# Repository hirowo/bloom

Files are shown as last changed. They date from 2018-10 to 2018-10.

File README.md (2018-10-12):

# Bloom
ArduinoNanoブートローダー入り小型電飾モジュール

## 概要
フルカラーLED(WS2812B)をArduinoでコントロールするとき、
Arduinoのサイズが大きく小型のものに組み込みにくい、ということはありませんか？

本モジュールは、ArduinoNanoのブートローダーが組み込まれた小型のモジュールで、
衣装や小道具など、小型のものに組み込むことができます。

もちろん、ArduinoIDEでプログラムの開発を行うことができ、
プログラムを書き込むためのUSBシリアル変換モジュールも搭載しています。

## 特徴
本モジュールは2.4Aまで電流を流せるようにしており、
1個あたり最大50mA程度流すフルカラーLEDであれば、4,50個程度であれば光らせられます。

また、小型化のためおおよそのピンは削ってありますが、
アナログ入力ピン×2とボタンが実装されており、動作のトリガーとして利用できます。

## 使用可能ピン
フルカラーLEDシリアルピン:6  
基板実装ボタン:7  
A3ピン:A3  
A4ピン:A4  

## スペック
サイズ：36×20×5mm  
USBシリアル変換モジュール：FT232RL  

## ArduinoIDEでプログラムを書き換える方へ
ArduinoIDEのツールの設定は、ボード="Arduino Nano"、プロセッサ="ATmega328P"にしてください。

## （自作する人向け）ブートローダー及びヒューズ設定
下記サイトのNano3.1参照。  
https://trac.switch-science.com/wiki/ArduinoFuse#Nano3.1

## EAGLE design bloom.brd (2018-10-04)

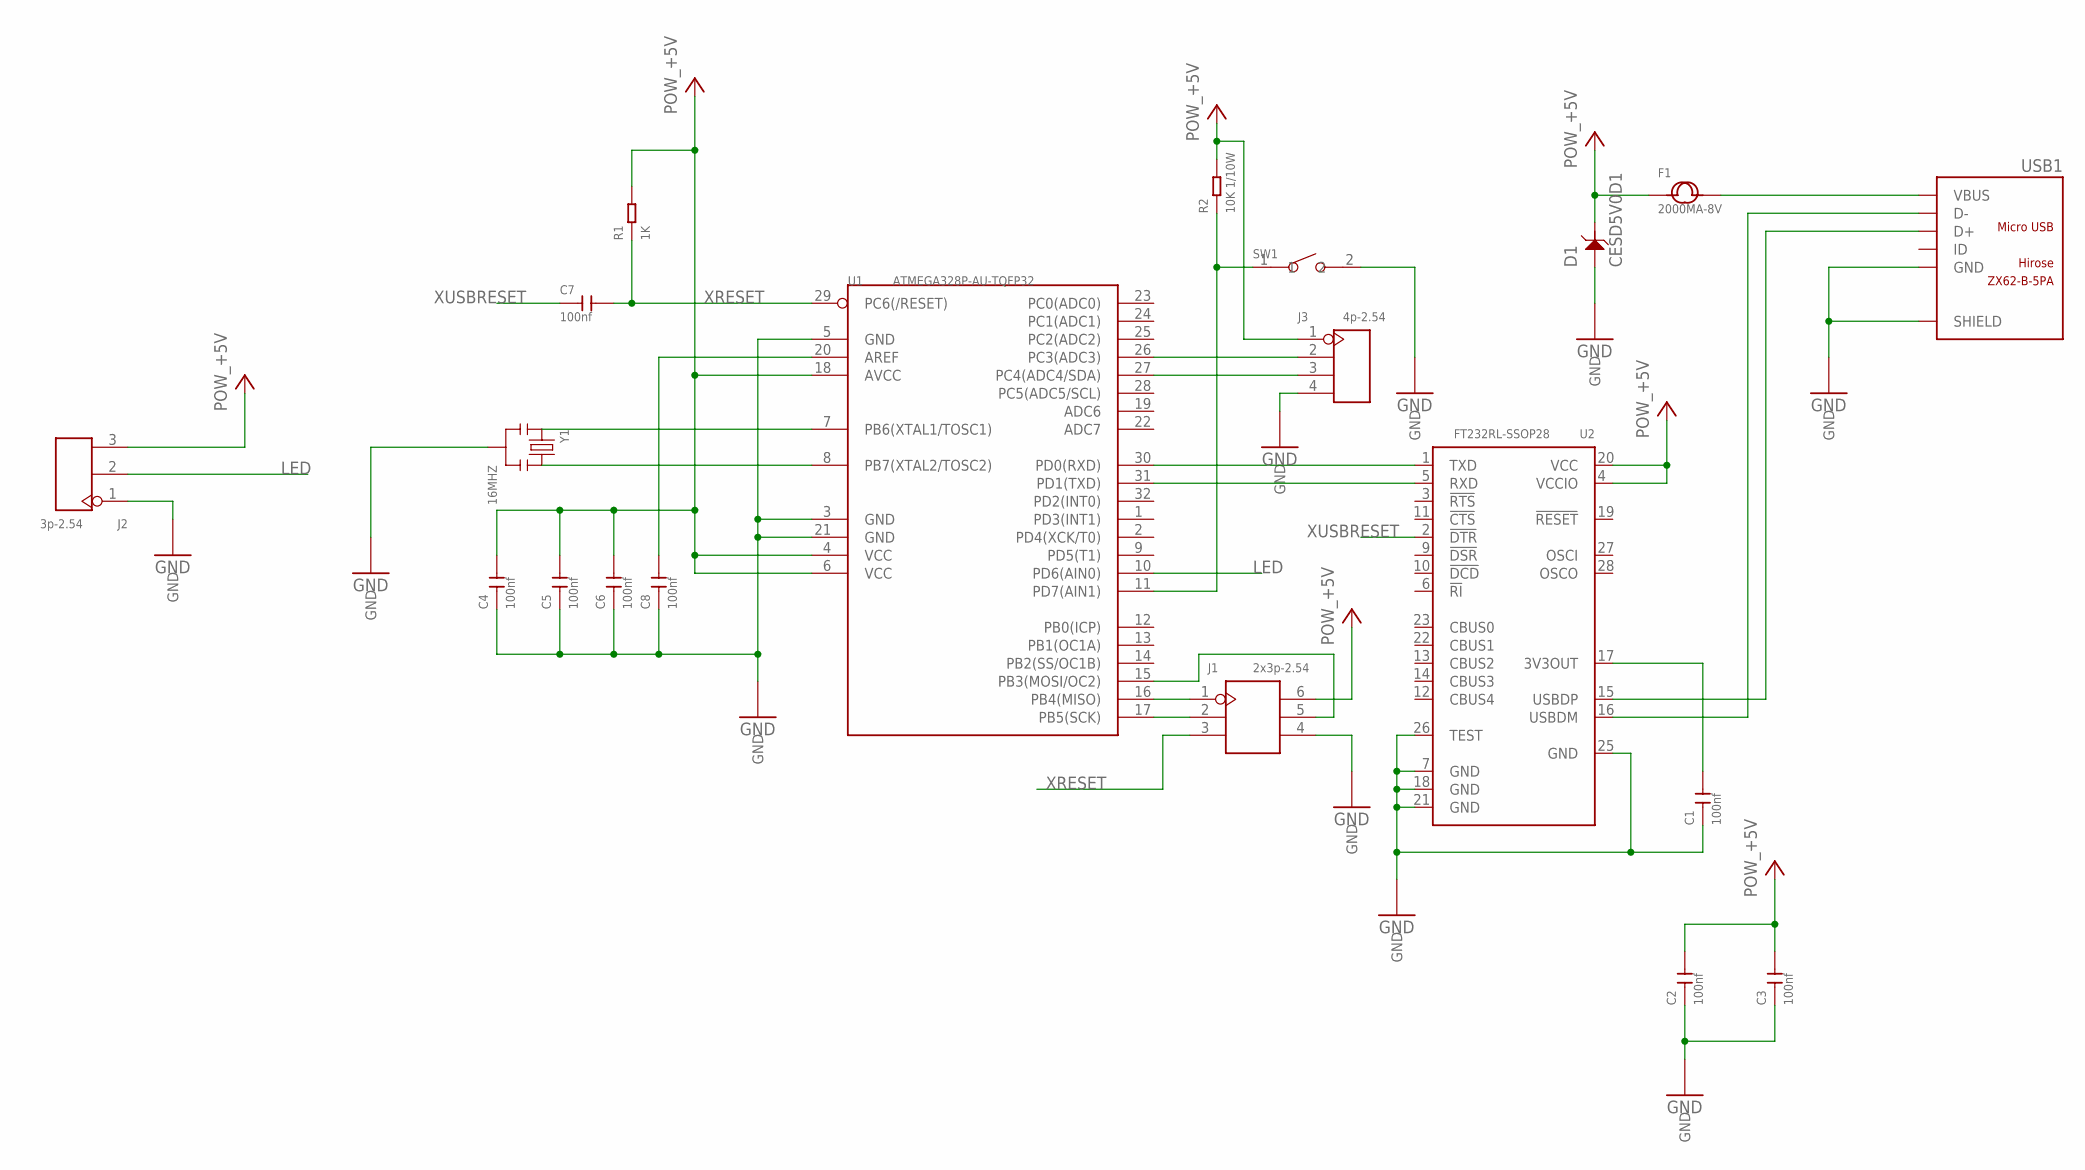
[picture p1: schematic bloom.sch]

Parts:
C1, C2, C3, C4, C5, C6, C7, C8: 100nf; C0402
D1: CESD5V0D1; SOD-123
F1: 2000MA-8V; F1210
J1: 2x3p-2.54; H2X3-2.54
J2: 3p-2.54; H3-2.54
J3: 4p-2.54; H4-2.54
R1: 1K; R0603
R2: 10K 1/10W; R0603
SW1: SMD-BUTTON(2P-3.0X2.5X1.2+0.4MM)-B3U-1000P-2P-SMD; SW2-2.6-3.0X2.5X1.2+0.4MM
U1: ATMEGA328P-AU-TQFP32; TQFP32-0.8-7X7MM
U2: FT232RL-SSOP28; SSOP28-0.65-10.2X5.2MM
USB1: ZX62-B-5PA; MICRO-USB5+6P-SMD-0.65-AB
Y1: 16MHZ; X3-SMD-3.6X1.3X0.8MM

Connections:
+5V: C2.2, C3.2, C4.2, C5.2, C6.2, D1.- (2), F1.1, J1.6, J2.3, J3.1, R1.2, R2.2, U1.4 (VCC), U1.6 (VCC), U1.18 (AVCC), U2.4 (VCCIO), U2.20 (VCC)
GND: C1.1, C2.1, C3.1, C4.1, C5.1, C6.1, C8.1, D1.+ (1), J1.4, J2.1, J3.4, SW1.2, U1.3 (GND), U1.5 (GND), U1.21 (GND), U2.7 (GND), U2.18 (GND), U2.21 (GND), U2.25 (GND), U2.26 (TEST), USB1.5 (GND), USB1.P1 (SHIELD), USB1.P2 (SHIELD), USB1.P3 (SHIELD), USB1.P4 (SHIELD), USB1.P5 (SHIELD), USB1.P6 (SHIELD), Y1.2
LED: J2.2, U1.10 (PD6(AIN0))
unnamed: C8.2, U1.20 (AREF)
unnamed: U1.30 (PD0(RXD)), U2.1 (TXD)
unnamed: U1.7 (PB6(XTAL1/TOSC1)), Y1.1
unnamed: U1.31 (PD1(TXD)), U2.5 (RXD)
unnamed: U2.15 (USBDP), USB1.3 (D+)
unnamed: U2.16 (USBDM), USB1.2 (D-)
unnamed: U1.8 (PB7(XTAL2/TOSC2)), Y1.3
unnamed: J1.1, U1.16 (PB4(MISO))
unnamed: J1.2, U1.17 (PB5(SCK))
unnamed: J1.5, U1.15 (PB3(MOSI/OC2))
unnamed: R2.1, SW1.1, U1.11 (PD7(AIN1))
unnamed: C1.2, U2.17 (3V3OUT)
unnamed: J3.2, U1.26 (PC3(ADC3))
unnamed: J3.3, U1.27 (PC4(ADC4/SDA))
VBUS: F1.2, USB1.1 (VBUS)
XRESET: C7.2, J1.3, R1.1, U1.29 (PC6(/RESET))
XUSBRESET: C7.1, U2.2 (!DTR)

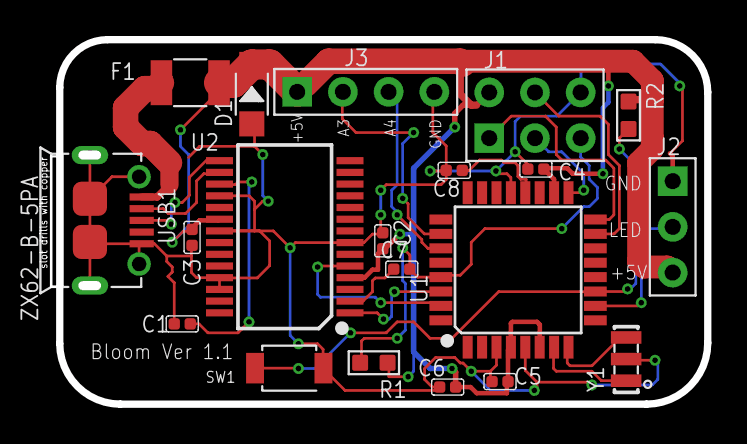
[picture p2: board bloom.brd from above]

Board: 2 copper layers, 36.0 x 20.2 mm, 20 parts (0 on the bottom side), 20 nets.

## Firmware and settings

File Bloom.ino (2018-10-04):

#include <Adafruit_NeoPixel.h>

#ifdef __AVR__
#include <avr/power.h>
#endif

//Bloom関連ピン
#define PIN_LED   6
#define PIN_BTN   7
#define PIN_A3    A3
#define PIN_A4    A4

#define LED_NUM       (40) // LEDの数
#define LED_MAX_SAT   80  // 最大彩度

// ボタン状態
#define PRESS_NONE 0
#define PRESS_NORMAL 1
#define PRESS_LONG 2

#define LONG_PRESS_MS 2000 // 長押し検知時間

// ガンマ補正データ
const uint8_t PROGMEM gamma8[] = {
  0,  0,  0,  0,  0,  0,  0,  0,  0,  0,  0,  0,  0,  0,  0,  0,
  0,  0,  0,  0,  0,  0,  0,  0,  0,  0,  0,  0,  1,  1,  1,  1,
  1,  1,  1,  1,  1,  1,  1,  1,  1,  2,  2,  2,  2,  2,  2,  2,
  2,  3,  3,  3,  3,  3,  3,  3,  4,  4,  4,  4,  4,  5,  5,  5,
  5,  6,  6,  6,  6,  7,  7,  7,  7,  8,  8,  8,  9,  9,  9, 10,
  10, 10, 11, 11, 11, 12, 12, 13, 13, 13, 14, 14, 15, 15, 16, 16,
  17, 17, 18, 18, 19, 19, 20, 20, 21, 21, 22, 22, 23, 24, 24, 25,
  25, 26, 27, 27, 28, 29, 29, 30, 31, 32, 32, 33, 34, 35, 35, 36,
  37, 38, 39, 39, 40, 41, 42, 43, 44, 45, 46, 47, 48, 49, 50, 50,
  51, 52, 54, 55, 56, 57, 58, 59, 60, 61, 62, 63, 64, 66, 67, 68,
  69, 70, 72, 73, 74, 75, 77, 78, 79, 81, 82, 83, 85, 86, 87, 89,
  90, 92, 93, 95, 96, 98, 99, 101, 102, 104, 105, 107, 109, 110, 112, 114,
  115, 117, 119, 120, 122, 124, 126, 127, 129, 131, 133, 135, 137, 138, 140, 142,
  144, 146, 148, 150, 152, 154, 156, 158, 160, 162, 164, 167, 169, 171, 173, 175,
  177, 180, 182, 184, 186, 189, 191, 193, 196, 198, 200, 203, 205, 208, 210, 213,
  215, 218, 220, 223, 225, 228, 231, 233, 236, 239, 241, 244, 247, 249, 252, 255
};

// Parameter 1 = number of pixels in strip
// Parameter 2 = Arduino pin number (most are valid)
// Parameter 3 = pixel type flags, add together as needed:
//   NEO_KHZ800  800 KHz bitstream (most NeoPixel products w/WS2812 LEDs)
//   NEO_KHZ400  400 KHz (classic 'v1' (not v2) FLORA pixels, WS2811 drivers)
//   NEO_GRB     Pixels are wired for GRB bitstream (most NeoPixel products)
//   NEO_RGB     Pixels are wired for RGB bitstream (v1 FLORA pixels, not v2)
//   NEO_RGBW    Pixels are wired for RGBW bitstream (NeoPixel RGBW products)
Adafruit_NeoPixel strip = Adafruit_NeoPixel(LED_NUM, PIN_LED, NEO_GRB + NEO_KHZ800);

void hsv2rgb(float h, float s, float v, uint8_t colors[3]) {
  int i;
  float f, p, q, t;

  h = max(0.0, min(360.0, h));
  s = max(0.0, min(100.0, s));
  v = max(0.0, min(100.0, v));

  s /= 100;
  v /= 100;

  if (s == 0) {
    // Achromatic (grey)
    colors[0] = colors[1] = colors[2] = round(v * 255);
    return;
  }

  h /= 60; // sector 0 to 5
  i = floor(h);
  f = h - i; // factorial part of h
  p = v * (1 - s);
  q = v * (1 - s * f);
  t = v * (1 - s * (1 - f));
  switch (i) {
    case 0:
      colors[0] = round(255 * v);
      colors[1] = round(255 * t);
      colors[2] = round(255 * p);
      break;
    case 1:
      colors[0] = round(255 * q);
      colors[1] = round(255 * v);
      colors[2] = round(255 * p);
      break;
    case 2:
      colors[0] = round(255 * p);
      colors[1] = round(255 * v);
      colors[2] = round(255 * t);
      break;
    case 3:
      colors[0] = round(255 * p);
      colors[1] = round(255 * q);
      colors[2] = round(255 * v);
      break;
    case 4:
      colors[0] = round(255 * t);
      colors[1] = round(255 * p);
      colors[2] = round(255 * v);
      break;
    default: // case 5:
      colors[0] = round(255 * v);
      colors[1] = round(255 * p);
      colors[2] = round(255 * q);
  }
}

void setLEDColor(float hue, float sat, float val) {
  uint8_t rgb_colors[3];

  //getRGB(hue, sat, val, rgb_colors); // converts HSB to RGB
  hsv2rgb(hue, sat, val, rgb_colors);
  for (uint8_t i = 0; i < LED_NUM; i++) {
    strip.setPixelColor(i,
                        pgm_read_byte(&gamma8[rgb_colors[0]]),
                        pgm_read_byte(&gamma8[rgb_colors[1]]),
                        pgm_read_byte(&gamma8[rgb_colors[2]]));
  }
  strip.show();
}

void setup() {
  pinMode(PIN_BTN, INPUT);
  
  strip.begin();
  strip.clear();
  strip.show();

  // 白く光る
  for (float count = 0; count <= 100.0F; count += 1.0F) {
    setLEDColor(0, 0, count);
    delay(10);
  }
  delay(500);

  for (float count = 0; count <= LED_MAX_SAT; count += 1.0F) {
    setLEDColor(0, count, 100);
    delay(5);
  }
  delay(2000);
}

// ボタン処理
int buttonTask() {
  static long pressTime;
  static bool isPress = false;
  static bool oldState = HIGH;
  bool btnState,toggled = false;
  
  btnState = digitalRead(PIN_BTN);
  if(btnState != oldState){
    oldState = btnState;
    if (btnState == LOW) {
      if (!isPress) {
        pressTime = millis();
        isPress = true;
      }
    } else {
      if (isPress) {
        isPress = false;
        return PRESS_NORMAL;
      }
    }
  }else if (isPress) {
    if (abs(millis() - pressTime) >= LONG_PRESS_MS) {
      isPress = false;
      return PRESS_LONG;
    }
  }
  return PRESS_NONE;
}

void loop()
{
  // 時間関係
  static float nowHue = 0;
  static long oldTime;
  static bool nextFlag = false; // 次回色変更フラグ
  long diff;
  int btnState;

  if (!nextFlag) {
    for (int count = 1; count <= (LED_MAX_SAT); count++) {
      setLEDColor(nowHue, LED_MAX_SAT - ((LED_MAX_SAT / 2) - abs((LED_MAX_SAT / 2) - count)), 100);
      delay(50);
      btnState = buttonTask();
      if (btnState != PRESS_NONE) {
        nextFlag = true;
        return;
      }
    }
  } else {
    nextFlag = false;
    //白になる
    for (int count = 1; count <= LED_MAX_SAT; count++) {
      setLEDColor(nowHue, LED_MAX_SAT - count, 100);
      delay(10);
      btnState = buttonTask();
      if (btnState != PRESS_NONE) {
        nextFlag = true;
        return;
      }
    }

    //45度移動
    nowHue += 45;
    if (nowHue >= 360) {
      nowHue = 0;
    }
    delay(200);

    //LED点灯
    for (int count = 1; count <= LED_MAX_SAT; count++) {
      setLEDColor(nowHue, count, 100);
      delay(10);
      btnState = buttonTask();
      if (btnState != PRESS_NONE) {
        nextFlag = true;
        return;
      }
    }
  }
}

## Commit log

2018-10-04 add new file
    [bloom.brd]
2018-10-04 Readmeを追加
2018-10-05 Readmeに説明を追加
